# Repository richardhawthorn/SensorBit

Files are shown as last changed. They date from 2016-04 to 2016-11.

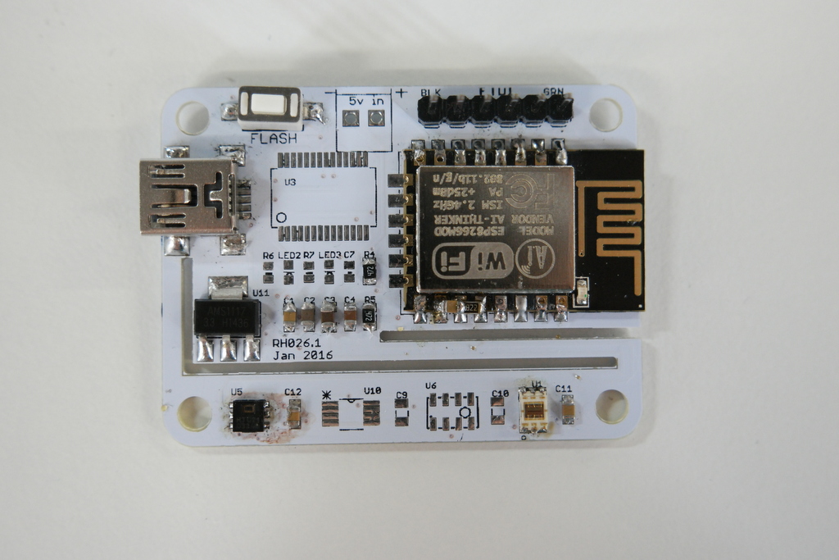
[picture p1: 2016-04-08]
images/image2.jpg

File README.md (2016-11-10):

### Description

The SensorBit, designed to collect and report various sensor readings over wifi.

### Sensors

- HTU21D (Temperature + Humidity)
- MCP9808 (Temperature)
- MPL3115A2 (Pressure)
- TSL2561 (Light)

### Other Features

- ESP8266
- 3.3V operation
- Mini USB power connector
- 5v power input terminal
- FTDI onboard
- Alternate FTDI programming port

### License

This work is licensed under a Creative Commons Attribution-ShareAlike 4.0 International License.

<br />
Designed by <a xmlns:cc="http://creativecommons.org/ns#" href="http://www.richardhawthorn.com" property="cc:attributionName" rel="cc:attributionURL" target="_blank">Richard Hawthorn</a><br />
<a rel="license" href="http://creativecommons.org/licenses/by-sa/4.0/" target="_blank">View License</a>

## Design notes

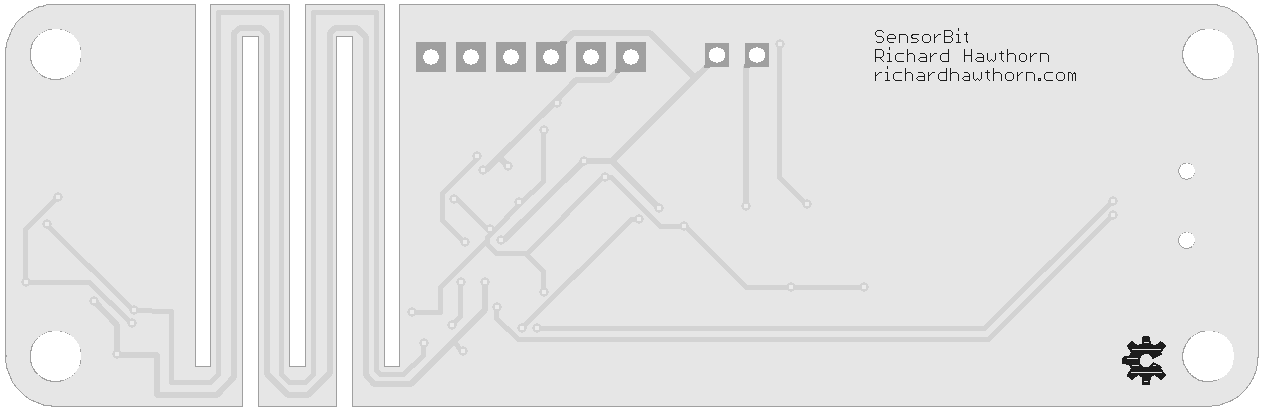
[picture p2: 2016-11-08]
images/pcb_back_v2.png

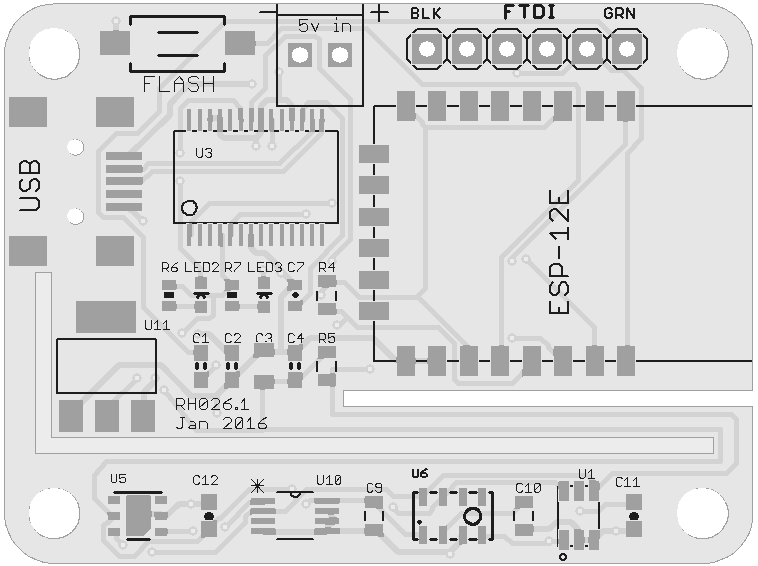
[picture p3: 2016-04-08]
images/pcb_front.png

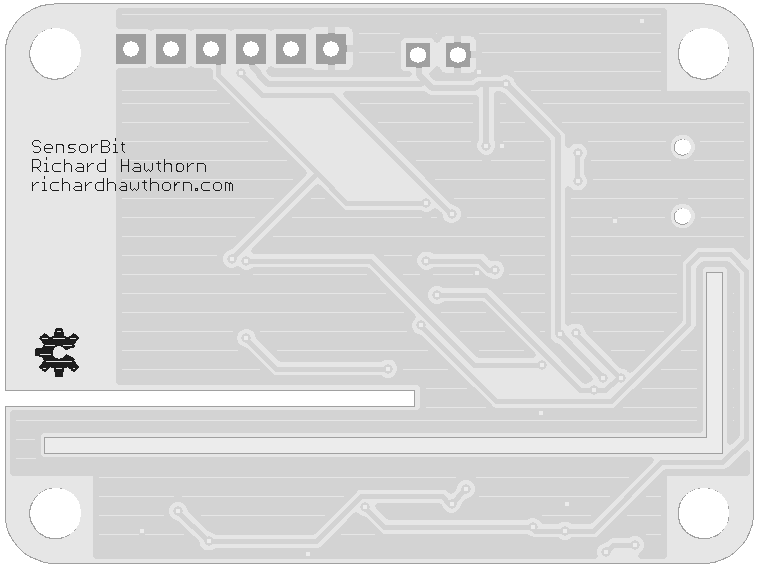
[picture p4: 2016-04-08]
images/pcb_back.png

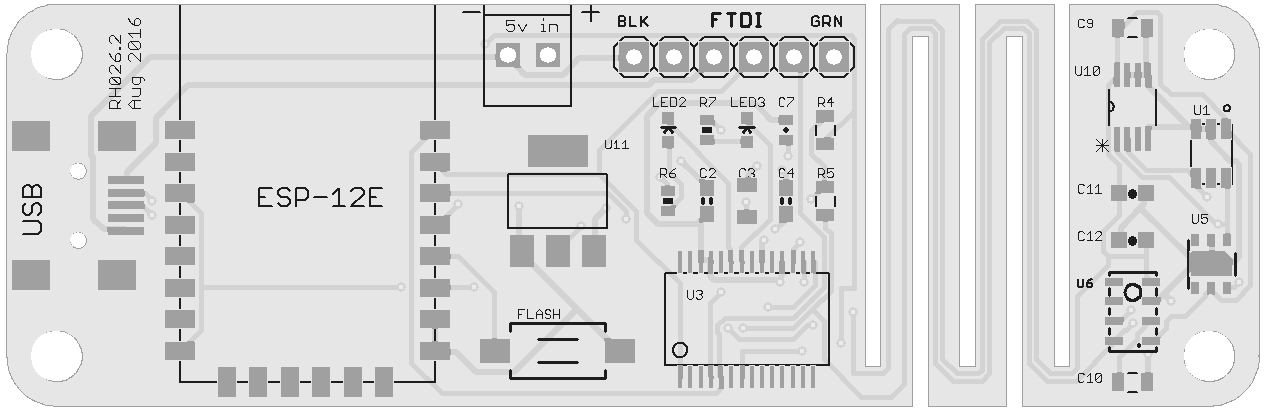
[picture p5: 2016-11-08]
images/pcb_front_v2.png

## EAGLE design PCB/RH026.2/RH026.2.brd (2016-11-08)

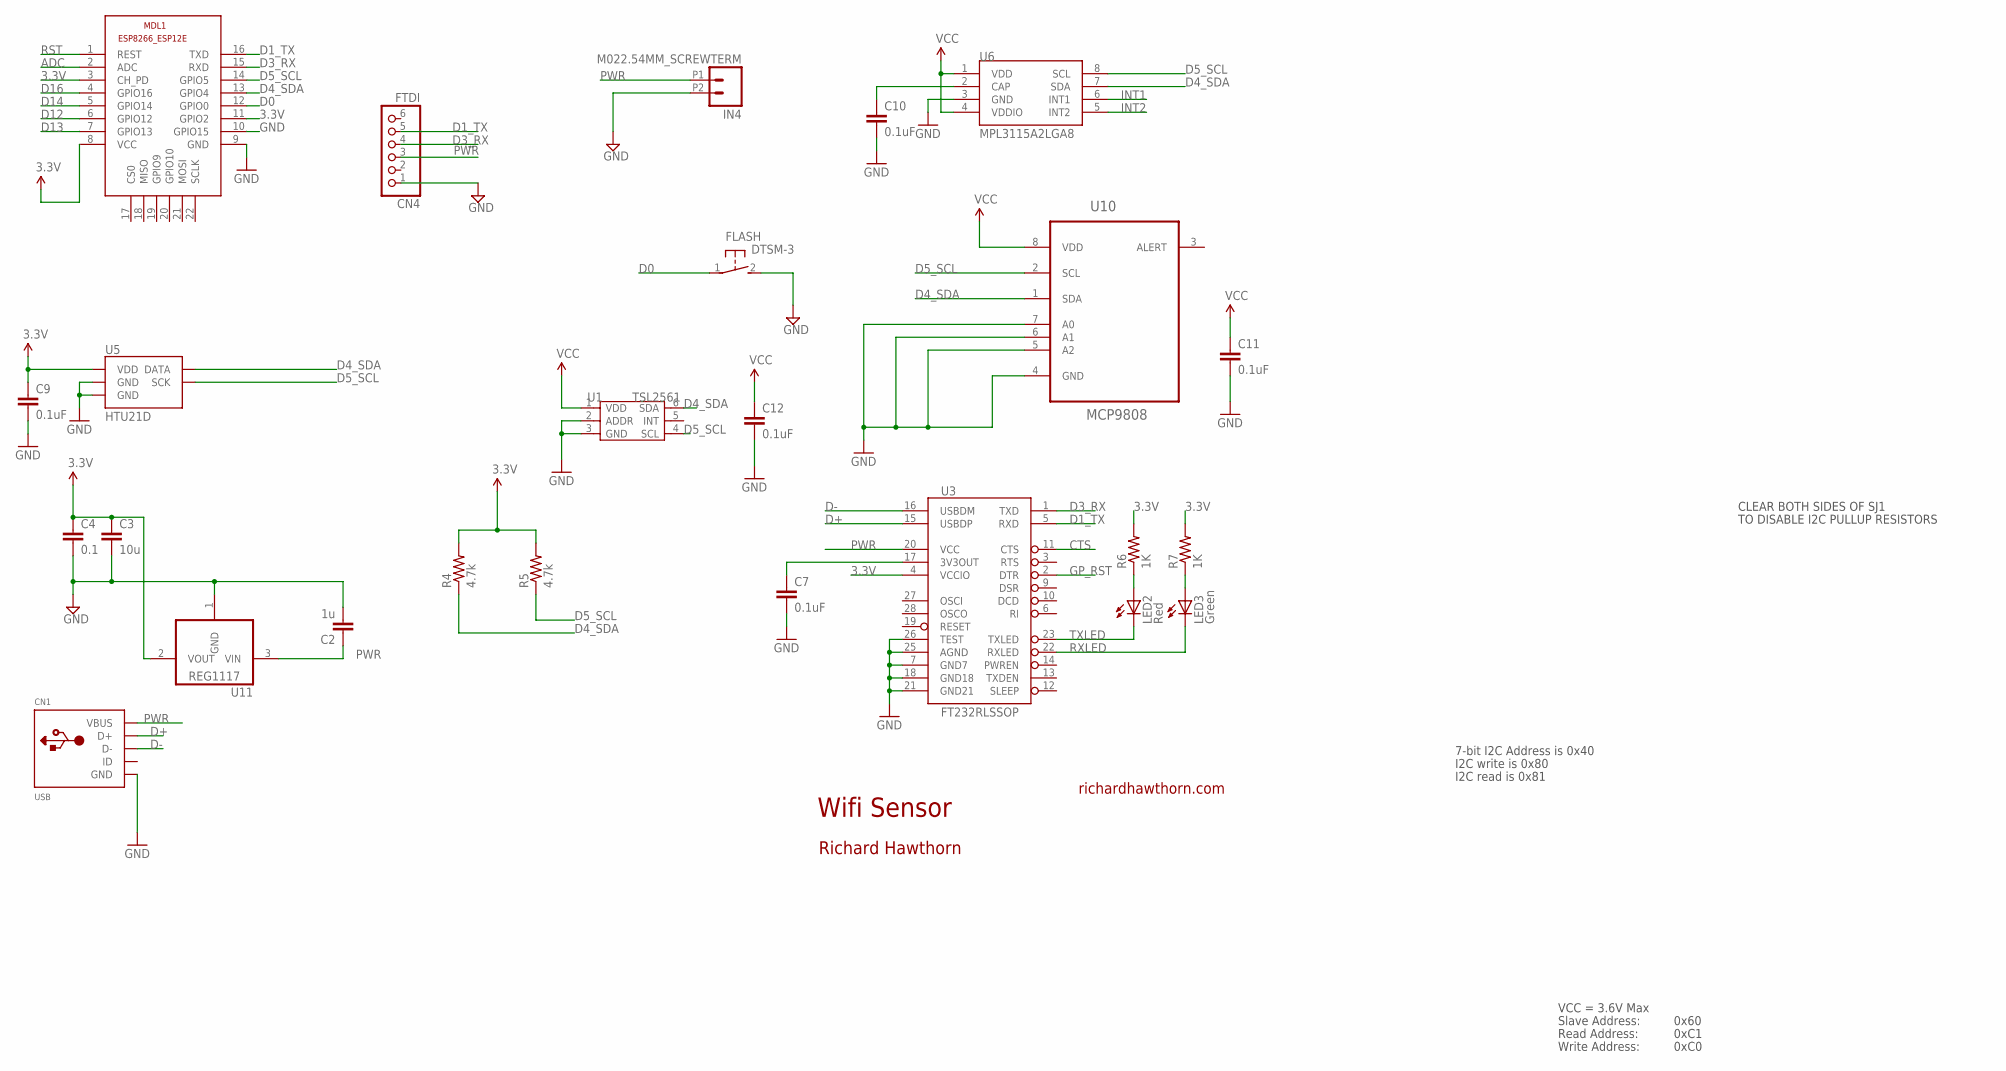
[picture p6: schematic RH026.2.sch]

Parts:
C2: 1u; 0603-CAP
C3: 10u; 0805-CAP
C4: 0.1; 0603-CAP
C7: 0.1uF; 0402-CAP
C9, C10: 0.1uF; 0805
C11, C12: 0.1uF; 0603-CAP
CN1: USB; USB-MINIB
CN4: FTDI; 1X06
FLASH: DTSM-3
IN4: M022.54MM_SCREWTERM; 1X02_2.54_SCREWTERM
LED2: Red; LED-0603
LED3: Green; LED-0603
MDL1: ESP8266-12EESP8266-ESP12E; ESP8266-ESP12E
R4, R5: 4.7k; 0805
R6, R7: 1K; 0402-RES
U1: TSL2561; TMB-6
U3: FT232RLSSOP; SSOP28DB
U5: HTU21D
U6: MPL3115A2LGA8; LGA8
U10: MCP9808; SOP65P490X110-8N
U11: REG1117; SOT223

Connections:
3.3V: C3.1, C4.1, C9.1, C11.1, C12.1, MDL1.3 (CH_PD), MDL1.8 (VCC), MDL1.11 (GPIO2), R4.2, R5.2, R6.2, R7.2, U1.1 (VDD), U3.4 (VCCIO), U5.VDD, U6.1 (VDD), U6.4 (VDDIO), U10.8 (VDD), U11.2 (VOUT)
3.3VOUT: C7.1, U3.17 (3V3OUT)
ADC: MDL1.2 (ADC)
CTS: U3.11 (CTS)
D0: FLASH.1, MDL1.12 (GPIO0)
D1_TX: CN4.5, MDL1.16 (TXD), U3.5 (RXD)
D3_RX: CN4.4, MDL1.15 (RXD), U3.1 (TXD)
D4_SDA: MDL1.13 (GPIO4), R4.1, U1.6 (SDA), U5.DATA, U6.7 (SDA), U10.1 (SDA)
D5_SCL: MDL1.14 (GPIO5), R5.1, U1.4 (SCL), U5.SCK, U6.8 (SCL), U10.2 (SCL)
D12: MDL1.6 (GPIO12)
D13: MDL1.7 (GPIO13)
D14: MDL1.5 (GPIO14)
D16: MDL1.4 (GPIO16)
D+: CN1.D+, U3.15 (USBDP)
D-: CN1.D-, U3.16 (USBDM)
GND: C2.2, C3.2, C4.2, C7.2, C9.2, C10.2, C11.2, C12.2, CN1.GND, CN4.1, FLASH.2, IN4.P2 (2), MDL1.9 (GND), MDL1.10 (GPIO15), U1.2 (ADDR), U1.3 (GND), U3.7 (GND7), U3.18 (GND18), U3.21 (GND21), U3.25 (AGND), U3.26 (TEST), U5.7 (GND), U5.GND, U6.3 (GND), U10.4 (GND), U10.5 (A2), U10.6 (A1), U10.7 (A0), U11.1 (GND)
GP_RST: U3.2 (DTR)
INT1: U6.6 (INT1)
INT2: U6.5 (INT2)
unnamed: LED2.A, R6.1
unnamed: LED3.A, R7.1
unnamed: C10.1, U6.2 (CAP)
PWR: C2.1, CN1.VBUS, CN4.3, IN4.P1 (1), U3.20 (VCC), U11.3 (VIN)
RST: MDL1.1 (REST)
RXLED: LED3.C, U3.22 (RXLED)
TXLED: LED2.C, U3.23 (TXLED)

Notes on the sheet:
Wifi Sensor
richardhawthorn.com
Richard Hawthorn
CLEAR BOTH SIDES OF SJ1
TO DISABLE I2C PULLUP RESISTORS
7-bit I2C Address is 0x40
I2C write is 0x80
I2C read is 0x81
VCC = 3.6V Max
Read Address:
Write Address:
Slave Address:
0x60
0xC1
0xC0

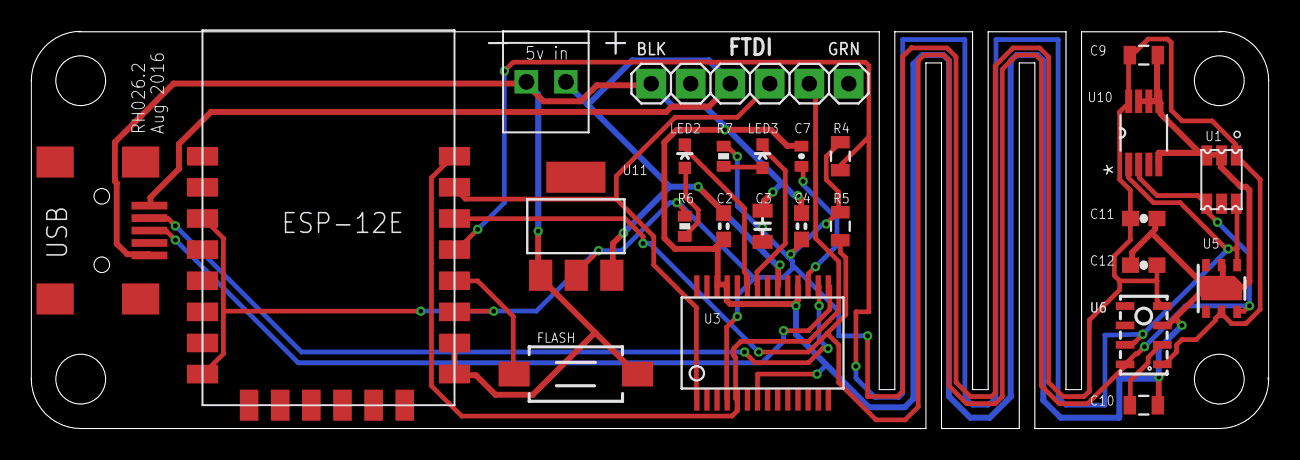
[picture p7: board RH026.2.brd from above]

Board: 2 copper layers, 79.5 x 25.5 mm, 26 parts (1 on the bottom side), 16 nets.

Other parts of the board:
U$3: OSHW-LOGO-S

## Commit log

2016-04-08 First version
    [RH026.1.brd, RH026.1.sch]
2016-11-08 Adding version 2 of the pcb
    [RH026.2.brd, RH026.2.sch]

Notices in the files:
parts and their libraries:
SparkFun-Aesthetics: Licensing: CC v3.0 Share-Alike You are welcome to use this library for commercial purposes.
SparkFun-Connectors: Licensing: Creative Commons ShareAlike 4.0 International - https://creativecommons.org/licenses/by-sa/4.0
